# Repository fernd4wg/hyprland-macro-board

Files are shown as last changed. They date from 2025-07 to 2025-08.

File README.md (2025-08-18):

# Hyprland Macro Board
  A fully custom macro board designed to improve workflow on Hyprland or any related window managers.

# LCD Image Help
  It might be that you do not like the images I've used for the LCD Screen (in hyprland-macro-board/macro-board-images/). If that is the case I would recommend using https://javl.github.io/image2cpp/ to 
convert images. You can make your own 128x32 (recommended) or get images off the internet and have image2cpp monochrome and resize them for you.

# Copying Keyboard Firmware to qmk_firmware Directory 
  Copy /hyprland-macro-board/hyprmacroboard into where your qmk_firmware/keyboards directory is so you can easily flash the firmware. Do this in the /hypr-macro-board directory

``` 
cp hyprmacroboard /PATH/TO/YOUR/QMK/KEYBOARD/DIR
```

# Compiling and Flashing
* Compile and Flash Firmware:
``` 
qmk compile -kb hyprmacroboard -km default
```

# Things to know 
  Resetting the board is annoying 9_9. All the components that are not the switches do not fit into their respective places so do not print the case parts until this message is not in this file.

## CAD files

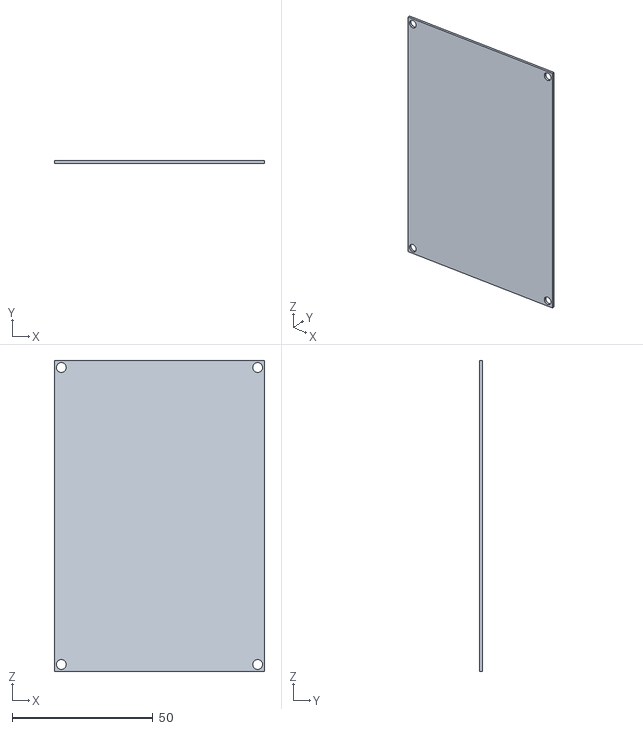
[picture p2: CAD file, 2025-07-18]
3d-models/case/Part Studio 1 - Part 3.stl
74.8 x 1.00 x 110.6

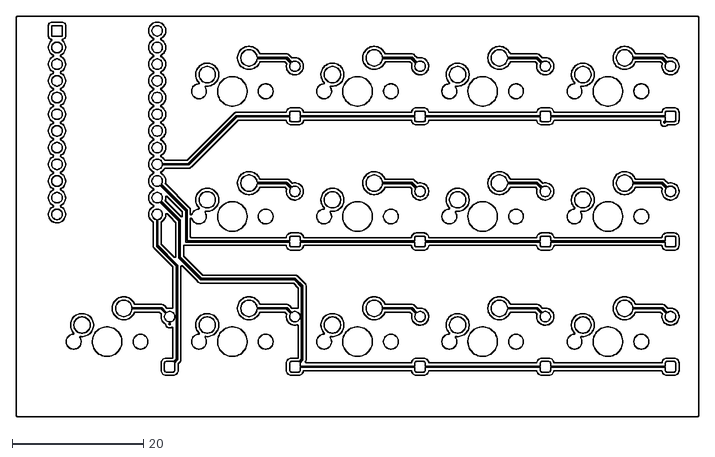
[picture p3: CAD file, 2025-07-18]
kicad-files/ky1-F_Cu.dxf
103.8 x 60.9

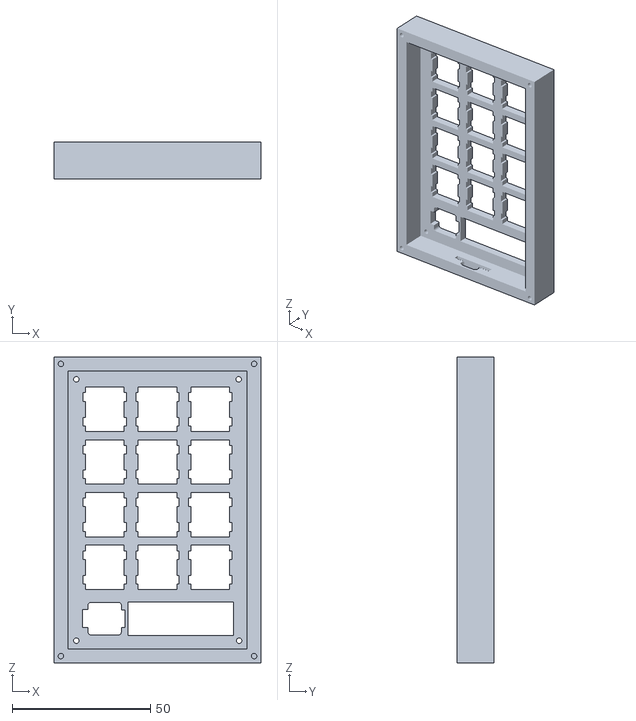
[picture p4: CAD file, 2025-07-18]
3d-models/case/Part Studio 1 - Part 2.stl
74.8 x 13.5 x 110.6

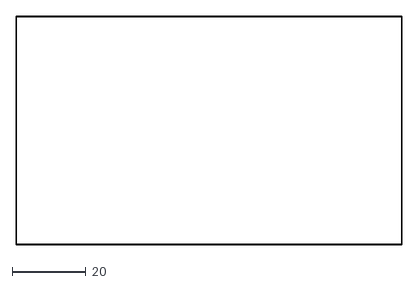
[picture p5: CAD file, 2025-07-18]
kicad-files/ky1-Edge_Cuts.dxf
104.8 x 62.0

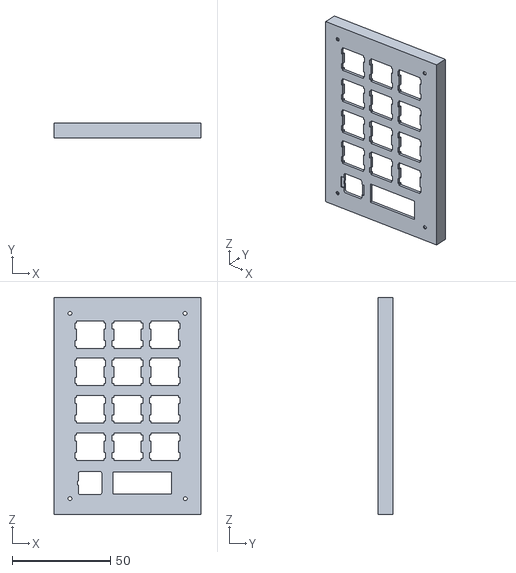
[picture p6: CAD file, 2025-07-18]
3d-models/case/Part Studio 1 - Part 1.stl
74.8 x 7.50 x 110.6

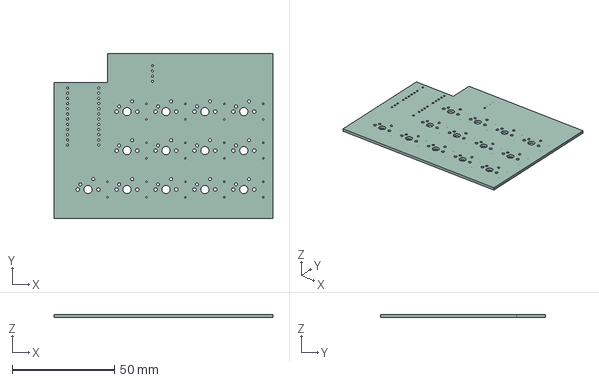
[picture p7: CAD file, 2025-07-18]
kicad-files/ky1234.step
107.2 x 81.0 x 1.51 mm

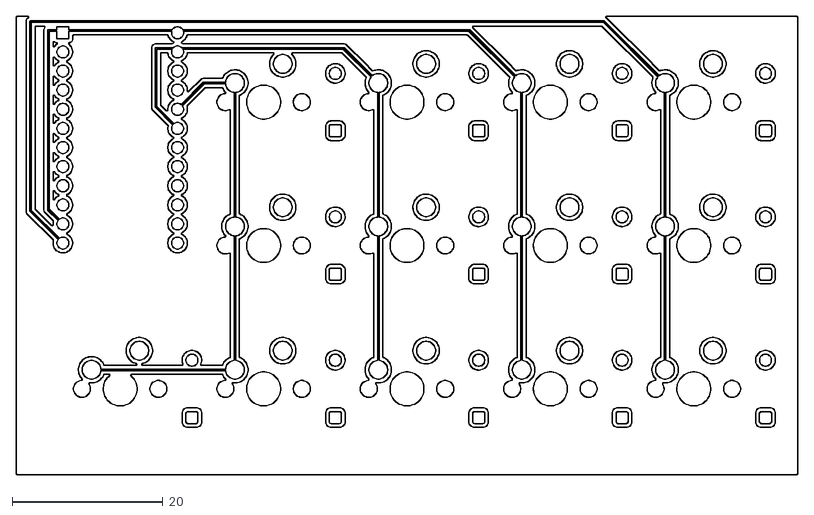
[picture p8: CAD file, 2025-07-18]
kicad-files/ky1-B_Cu.dxf
103.8 x 60.9

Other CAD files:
kicad-files/ky123.step
kicad-files/ky1-B_Mask.dxf
kicad-files/ky1-B_Paste.dxf
kicad-files/ky1-B_Silkscreen.dxf
kicad-files/ky1-F_Mask.dxf
kicad-files/ky1-F_Paste.dxf
kicad-files/ky1-F_Silkscreen.dxf

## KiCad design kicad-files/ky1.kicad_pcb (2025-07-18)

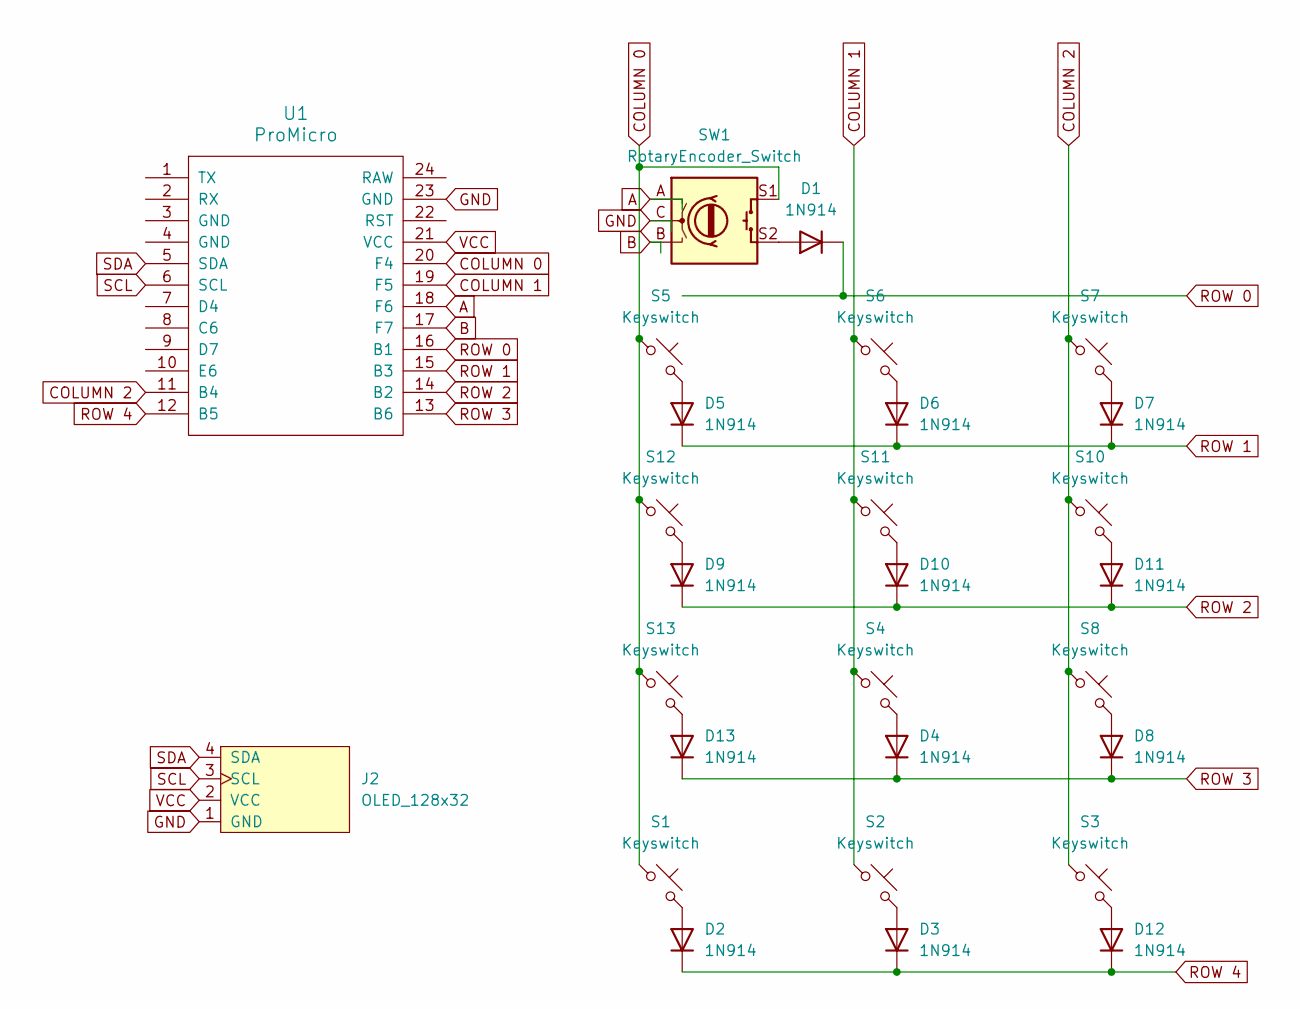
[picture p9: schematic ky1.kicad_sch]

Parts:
D1, D2, D3, D4, D5, D6, D7, D8, D9, D10, D11, D12, D13: 1N914; D_DO-35_SOD27_P7.62mm_Horizontal
J2: OLED_128x32
S1, S2, S3, S4, S5, S6, S7, S8, S10, S11, S12, S13: Keyswitch; SW_Cherry_MX_PCB_1.00u
SW1: RotaryEncoder_Switch; RotaryEncoder_Alps_EC11E-Switch_Vertical_H20mm
U1: ProMicro; ProMicro-EnforcedTop

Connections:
A: SW1.A, U1.18 (F6)
B: SW1.B, U1.17 (F7)
COLUMN 0: S1.1, S5.1, S12.1, S13.1, SW1.S1, U1.20 (F4)
COLUMN 1: S2.1, S4.1, S6.1, S11.1, U1.19 (F5)
COLUMN 2: S3.1, S7.1, S8.1, S10.1, U1.11 (B4)
GND: J2.1 (GND), SW1.C, U1.23 (GND)
unnamed: D1.2 (A), SW1.S2
unnamed: D2.2 (A), S1.2
unnamed: D3.2 (A), S2.2
unnamed: D4.2 (A), S4.2
unnamed: D5.2 (A), S5.2
unnamed: D6.2 (A), S6.2
unnamed: D7.2 (A), S7.2
unnamed: D8.2 (A), S8.2
unnamed: D9.2 (A), S12.2
unnamed: D10.2 (A), S11.2
unnamed: D11.2 (A), S10.2
unnamed: D12.2 (A), S3.2
unnamed: D13.2 (A), S13.2
ROW 0: D1.1 (K), U1.16 (B1)
ROW 1: D5.1 (K), D6.1 (K), D7.1 (K), U1.15 (B3)
ROW 2: D9.1 (K), D10.1 (K), D11.1 (K), U1.14 (B2)
ROW 3: D4.1 (K), D8.1 (K), D13.1 (K), U1.13 (B6)
ROW 4: D2.1 (K), D3.1 (K), D12.1 (K), U1.12 (B5)
SCL: J2.3 (SCL), U1.6 (SCL)
SDA: J2.4 (SDA), U1.5 (SDA)
VCC: J2.2 (VCC), U1.21 (VCC)

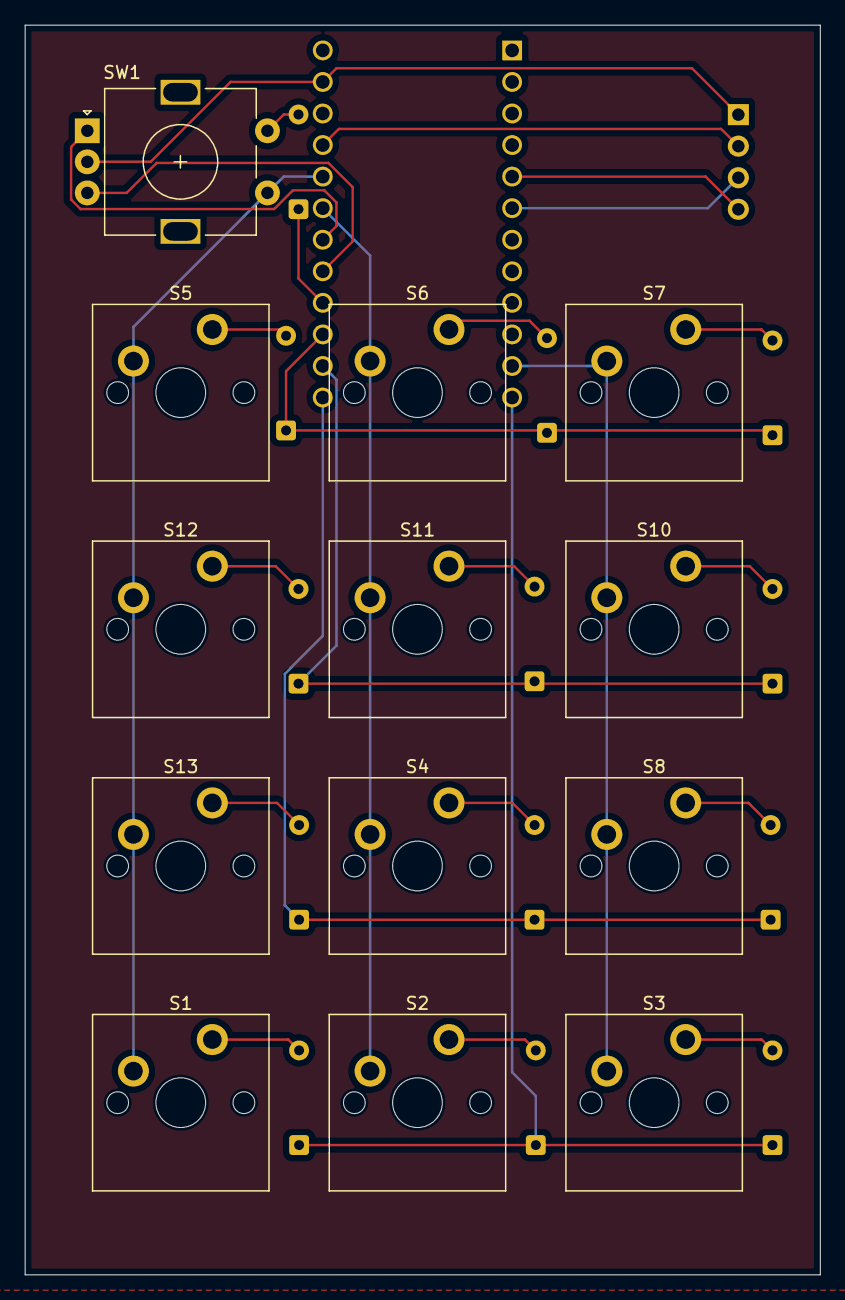
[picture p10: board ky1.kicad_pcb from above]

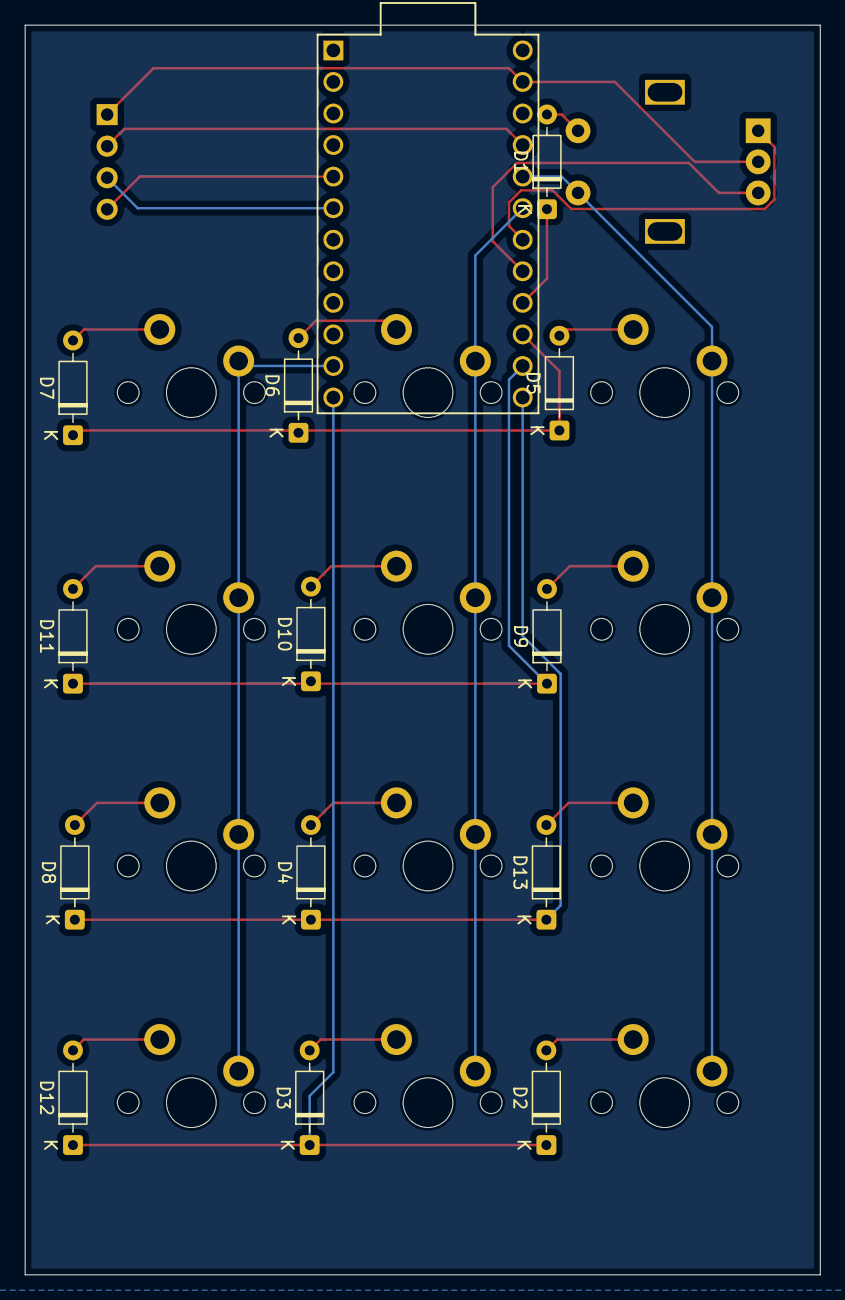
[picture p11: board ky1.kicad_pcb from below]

Board: 2 copper layers, 64.0 x 100.6 mm, 28 parts (14 on the bottom side), 27 nets.

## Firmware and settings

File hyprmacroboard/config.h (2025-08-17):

#pragma once

#define ENCODER_MAP_KEY_DELAY 10
// matrix size
#define MATRIX_ROWS 5
#define MATRIX_COLS 3

#define NUM_ENCODERS 1
#define NUM_DIRECTIONS 2
// oled display
#define OLED_BRIGHTNESS 128
#define OLED_DISPLAY_128X32
#define I2C1_SDA_PIN D1
#define I2C1_SCL_PIN D0

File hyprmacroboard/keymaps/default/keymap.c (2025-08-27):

#include QMK_KEYBOARD_H
#include "timer.h"

// #define OLED_TIMEOUT 10000

uint16_t last_input_time = 0;
layer_state_t last_layer_state = 0;

enum layerNames {
  _HYPRLAND,
  _VIM,
  _GENERAL, // general & browser
  _FN,
  _NUMPAD,
  _NUM_LAYERS
};

// cusotm keycode for cycling through layers
enum custom_keycodes {
    CYCLE_LAYER = SAFE_RANGE,
};

layer_state_t layer_state_set_user(layer_state_t state) {
    if (get_highest_layer(state) != get_highest_layer(last_layer_state)) {
        last_input_time = timer_read();
        last_layer_state = state;
    }
    return state;
}

#if defined(ENCODER_MAP_ENABLE)
    const uint16_t PROGMEM encoder_map[][NUM_ENCODERS][NUM_DIRECTIONS] = {
        [0] = { ENCODER_CCW_CW(KC_VOLD, KC_VOLU) },
        [1] = { ENCODER_CCW_CW(KC_VOLD, KC_VOLU) },
        [2] = { ENCODER_CCW_CW(KC_VOLD, KC_VOLU) },
        [3] = { ENCODER_CCW_CW(KC_VOLD, KC_VOLU) },
        [4] = { ENCODER_CCW_CW(KC_VOLD, KC_VOLU) },
    };
#endif

#ifdef OLED_ENABLE
// rotate led because its upside down
oled_rotation_t oled_init_user(oled_rotation_t rotation) {
    return OLED_ROTATION_180;
}

oled_write_P(PSTR("Layer: "), false);

    switch (get_highest_layer(layer_state)) {
        case _HYPRLAND:
            oled_write_P(PSTR("HYPRLAND\n"), false);
            break;
        case _VIM:
            oled_write_P(PSTR("VIM\n"), false);
            break;
        case _GENERAL:
            oled_write_P(PSTR("GENERAL\n"), false);
            break;
        case _FN: 
            oled_write_P(PSTR("FN\n"), false);
            break;
        case _NUMPAD:
            oled_write_P(PSTR("NUMPAD\n"), false);
            break;
        default:
            // Or use the write_ln shortcut over adding '\n' to the end of your string
            oled_write_ln_P(PSTR("Undefined"), false);
}
#endif

const uint16_t PROGMEM keymaps[][MATRIX_ROWS][MATRIX_COLS] = {
  // HYPRLAND LAYOUT
  [_HYPRLAND] = LAYOUT(
    CYCLE_LAYER, XXXXXXX, XXXXXXX, // cycle to next layer
    G(KC_F), G(KC_SPC), G(KC_C),
    G(KC_Q), G(KC_B), G(KC_D),
    G(KC_COMM), G(KC_UP), G(KC_DOT),
    G(KC_LEFT), G(KC_DOWN), G(KC_RIGHT)
  ),
  // VIM LAYOUT
  [_VIM] = LAYOUT(
    CYCLE_LAYER, XXXXXXX, XXXXXXX, // cycle to next layer
    KC_ESC, KC_V, KC_I, // modes: normal, visual, insert
    KC_D, KC_G, KC_SPACE,
    KC_QUOTE, KC_K, KC_RIGHT_BRACKET,
    KC_H, KC_K, KC_L
  ),
  // GENERAL & BROWSER LAYOUT
  [_GENERAL] = LAYOUT(
    CYCLE_LAYER, XXXXXXX, XXXXXXX, // cycle to next layer
    C(KC_C), C(KC_V), C(KC_Z),
    C(KC_T), C(KC_W), C(KC_L),
    C(KC_TAB), C(S(KC_TAB)), C(KC_R),
    C(S(KC_T)),A(KC_LEFT), A(KC_RIGHT)
  ),
  // FUNCTION
  [_FN] = LAYOUT(
    CYCLE_LAYER, XXXXXXX, XXXXXXX, // cycle to next layer
    KC_F1, KC_F2, KC_F3,
    KC_F4, KC_F5, KC_F6,
    KC_F7, KC_F8, KC_F9,
    KC_F10, KC_F11, KC_F12

  ),
  // NUMPAD
  [_NUMPAD] = LAYOUT(
    CYCLE_LAYER, XXXXXXX, XXXXXXX, // cycle to next layer
    KC_1, KC_2, KC_3,
    KC_4, KC_5, KC_6,
    KC_7, KC_8, KC_9,
    KC_0, KC_DOT, KC_MINS

  )
};

// function to cycle through layers
bool process_record_user(uint16_t keycode, keyrecord_t *record) {
    switch (keycode) {
        case CYCLE_LAYER:
            if (record->event.pressed) {
                static uint8_t current_layer = _HYPRLAND;
                current_layer = (current_layer + 1) % _NUM_LAYERS;
                layer_move(current_layer);
            }
        return false;
    }
    return true;
}
